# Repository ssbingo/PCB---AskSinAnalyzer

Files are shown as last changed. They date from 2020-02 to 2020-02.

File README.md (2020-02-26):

# PCB für den AskSinAnalyzer

## Bilder

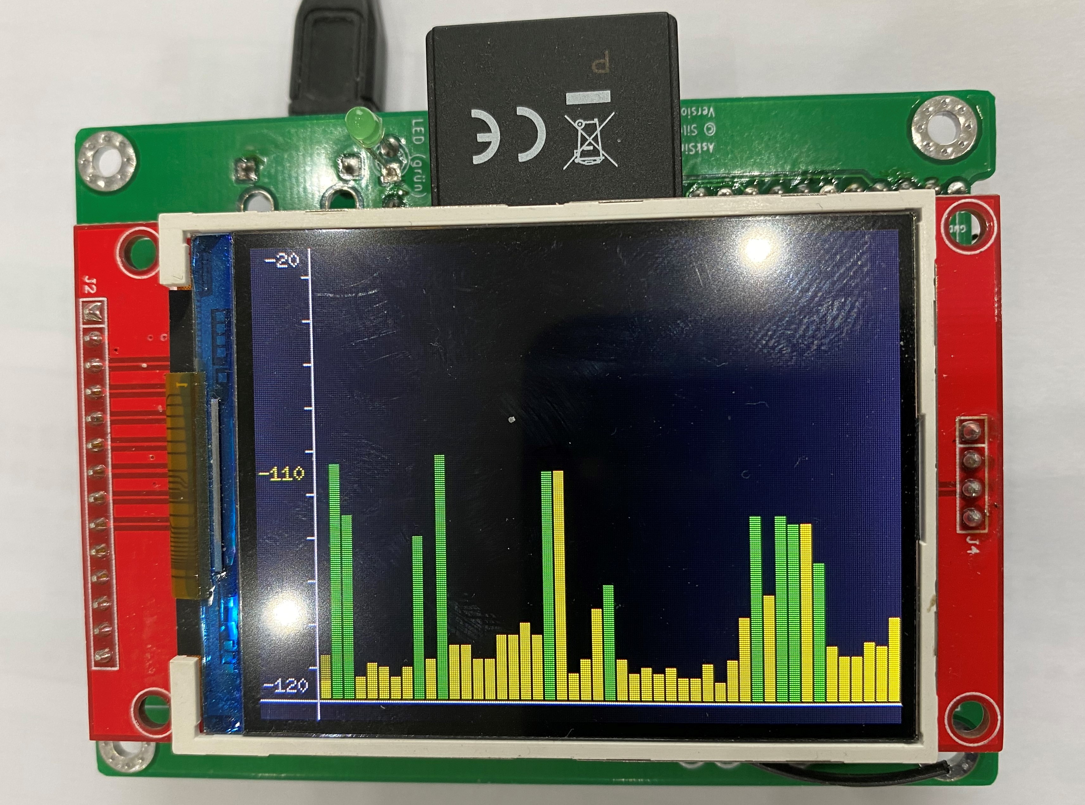
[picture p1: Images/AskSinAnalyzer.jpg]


## Schaltplan

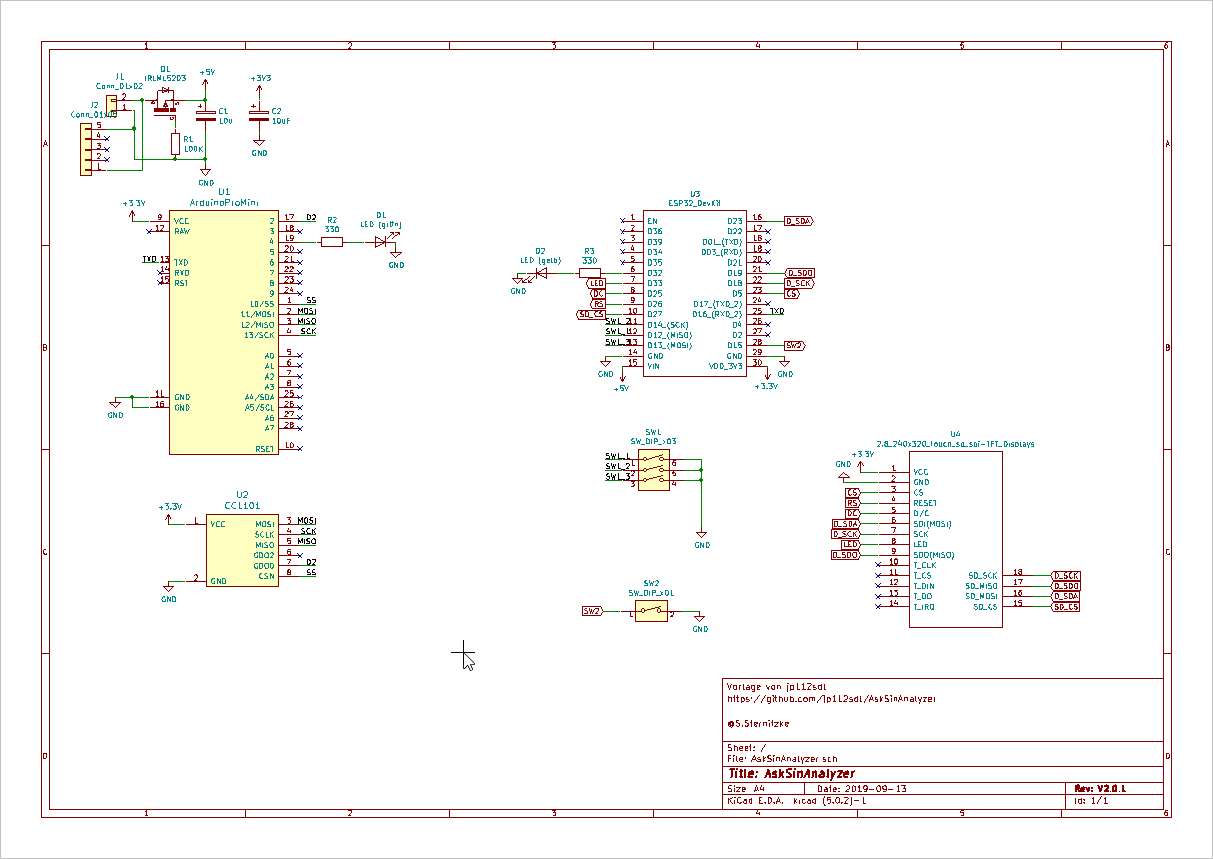
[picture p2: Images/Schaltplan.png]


[:arrow_right: Schaltplan](Images/Schaltplan.pdf)

## Platine

[:arrow_right: PCB Gerber](Platine/AskSinAnalyzer V2.0.3.zip)

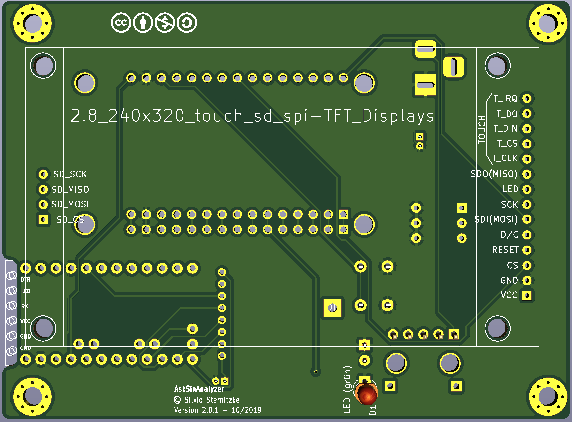
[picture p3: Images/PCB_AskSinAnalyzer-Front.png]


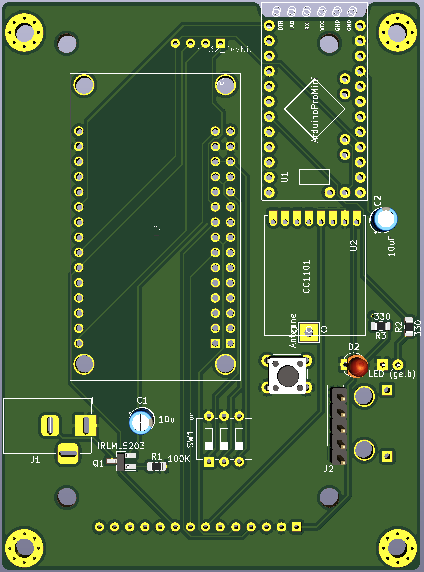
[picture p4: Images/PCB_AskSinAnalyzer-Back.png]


## Gehäuse

## Aufbau / Stückliste

### Der Aufbau
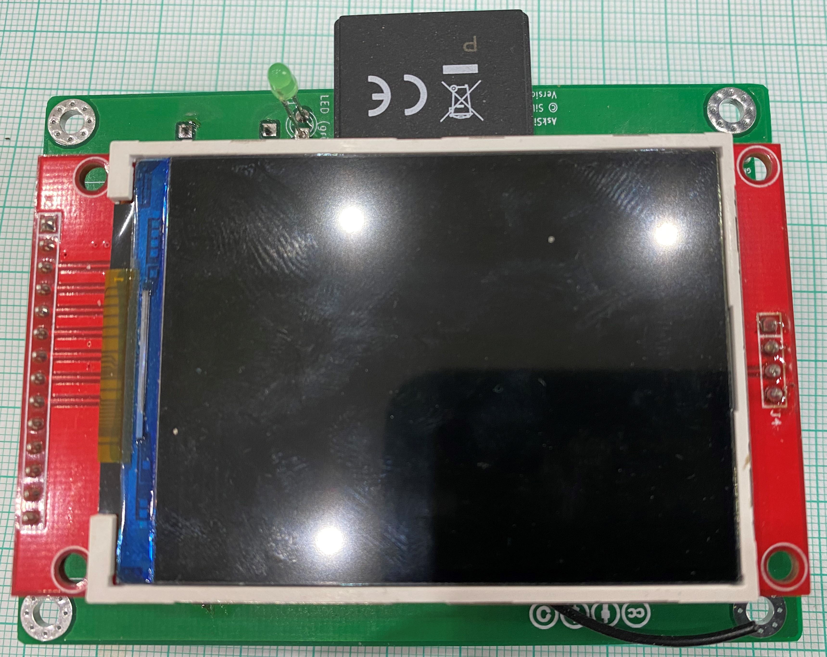
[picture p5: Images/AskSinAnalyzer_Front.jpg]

Bestückung Frontseite<br>

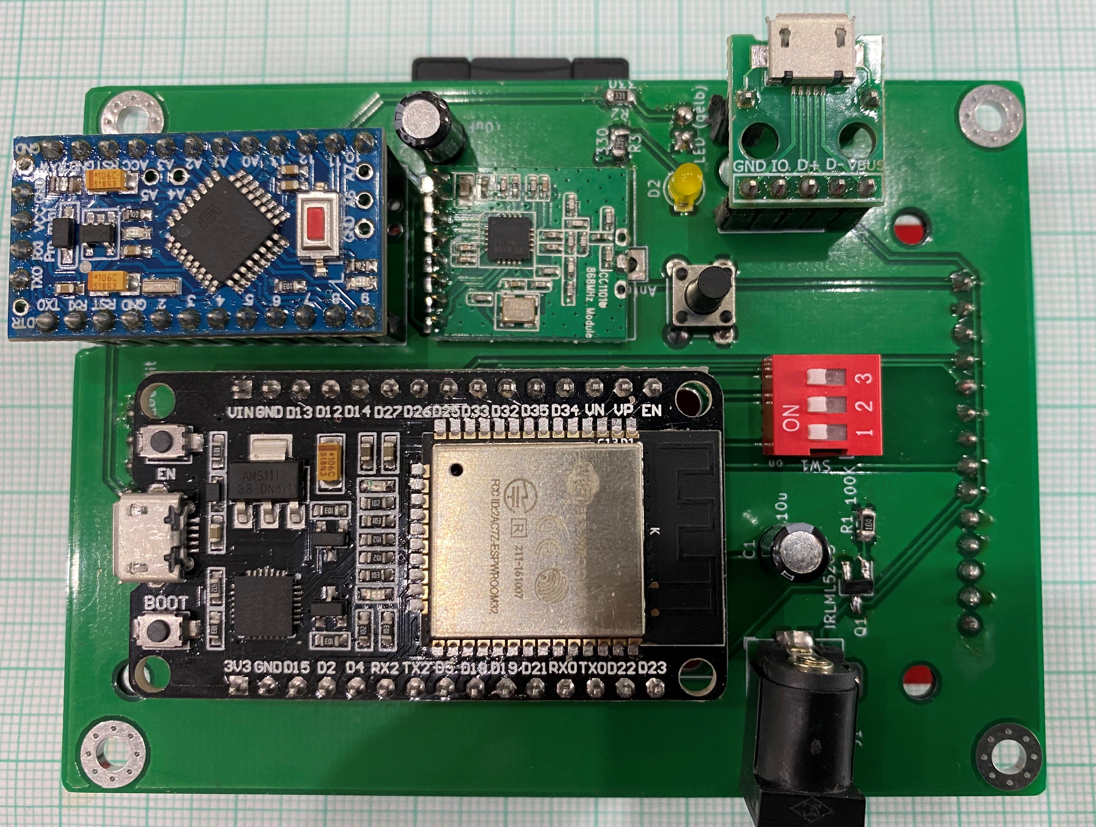
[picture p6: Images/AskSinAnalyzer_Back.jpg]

Bestückung Rückseite<br>
Hier gut zu erkennen, der verwendetet ESP32. Das PinOut ist etwas anders.<br>


AskSinnAnalyzer in Betrieb<br>

### Die benötigten Bauteile
| Bauteil | Link |
| ---|---|
|Bauteilliste Reichelt|[:arrow_right: Reichelt](https://www.reichelt.de/my/1678090) |
|Arduinio Pro mini 3.3V | |
|Funkmodul CC1101| |
|Display 2.8 mit SPI|[:arrow_right: Ebay](https://www.ebay.de/itm/322625783359) |

## Hinweise

- :exclamation: Der verwendete ESP32 hatte ein, gegenüber der Beschreibung im Projekt, etwas verändertetes Layout. siehe [Beitrag im Forum](https://homematic-forum.de/forum/viewtopic.php?f=76&t=51161&p=527419#p527456]

## Lizenz

**Creative Commons BY-NC-SA**<br>
Give Credit, NonCommercial, ShareAlike

<br />This work is licensed under a <a rel="license" href="http://creativecommons.org/licenses/by-nc-sa/4.0/">Creative Commons Attribution-NonCommercial-ShareAlike 4.0 International License</a>.

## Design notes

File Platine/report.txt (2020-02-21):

Plot-Datei „H:\Eigene Platinen (KiCAD)\Projekte\In Bearbeitung\AskSinAnalyzer V2\Platine\Gerber\AskSinAnalyzer-F.Cu.gbr“ erstellt.
Plot-Datei „H:\Eigene Platinen (KiCAD)\Projekte\In Bearbeitung\AskSinAnalyzer V2\Platine\Gerber\AskSinAnalyzer-B.Cu.gbr“ erstellt.
Plot-Datei „H:\Eigene Platinen (KiCAD)\Projekte\In Bearbeitung\AskSinAnalyzer V2\Platine\Gerber\AskSinAnalyzer-F.Paste.gbr“ erstellt.
Plot-Datei „H:\Eigene Platinen (KiCAD)\Projekte\In Bearbeitung\AskSinAnalyzer V2\Platine\Gerber\AskSinAnalyzer-B.Paste.gbr“ erstellt.
Plot-Datei „H:\Eigene Platinen (KiCAD)\Projekte\In Bearbeitung\AskSinAnalyzer V2\Platine\Gerber\AskSinAnalyzer-F.SilkS.gbr“ erstellt.
Plot-Datei „H:\Eigene Platinen (KiCAD)\Projekte\In Bearbeitung\AskSinAnalyzer V2\Platine\Gerber\AskSinAnalyzer-B.SilkS.gbr“ erstellt.
Plot-Datei „H:\Eigene Platinen (KiCAD)\Projekte\In Bearbeitung\AskSinAnalyzer V2\Platine\Gerber\AskSinAnalyzer-F.Mask.gbr“ erstellt.
Plot-Datei „H:\Eigene Platinen (KiCAD)\Projekte\In Bearbeitung\AskSinAnalyzer V2\Platine\Gerber\AskSinAnalyzer-B.Mask.gbr“ erstellt.
Plot-Datei „H:\Eigene Platinen (KiCAD)\Projekte\In Bearbeitung\AskSinAnalyzer V2\Platine\Gerber\AskSinAnalyzer-Edge.Cuts.gbr“ erstellt.

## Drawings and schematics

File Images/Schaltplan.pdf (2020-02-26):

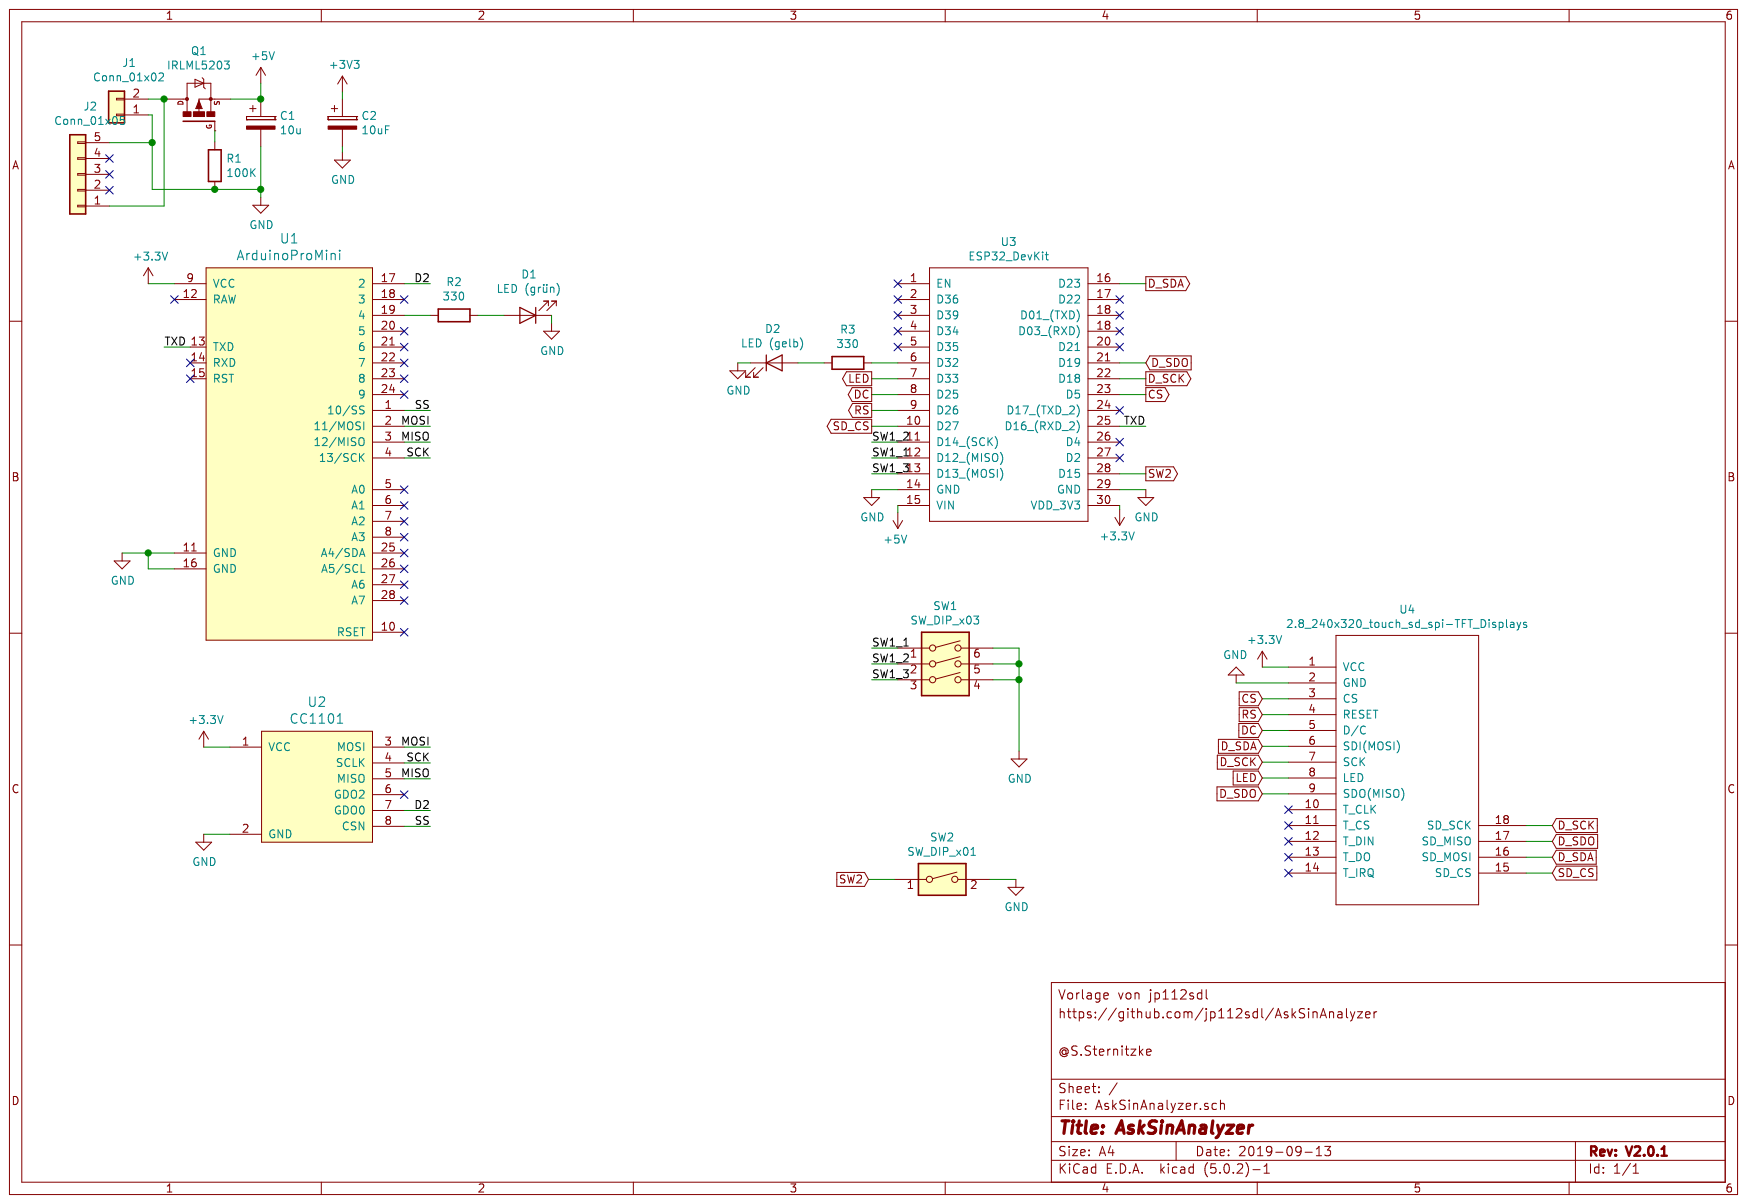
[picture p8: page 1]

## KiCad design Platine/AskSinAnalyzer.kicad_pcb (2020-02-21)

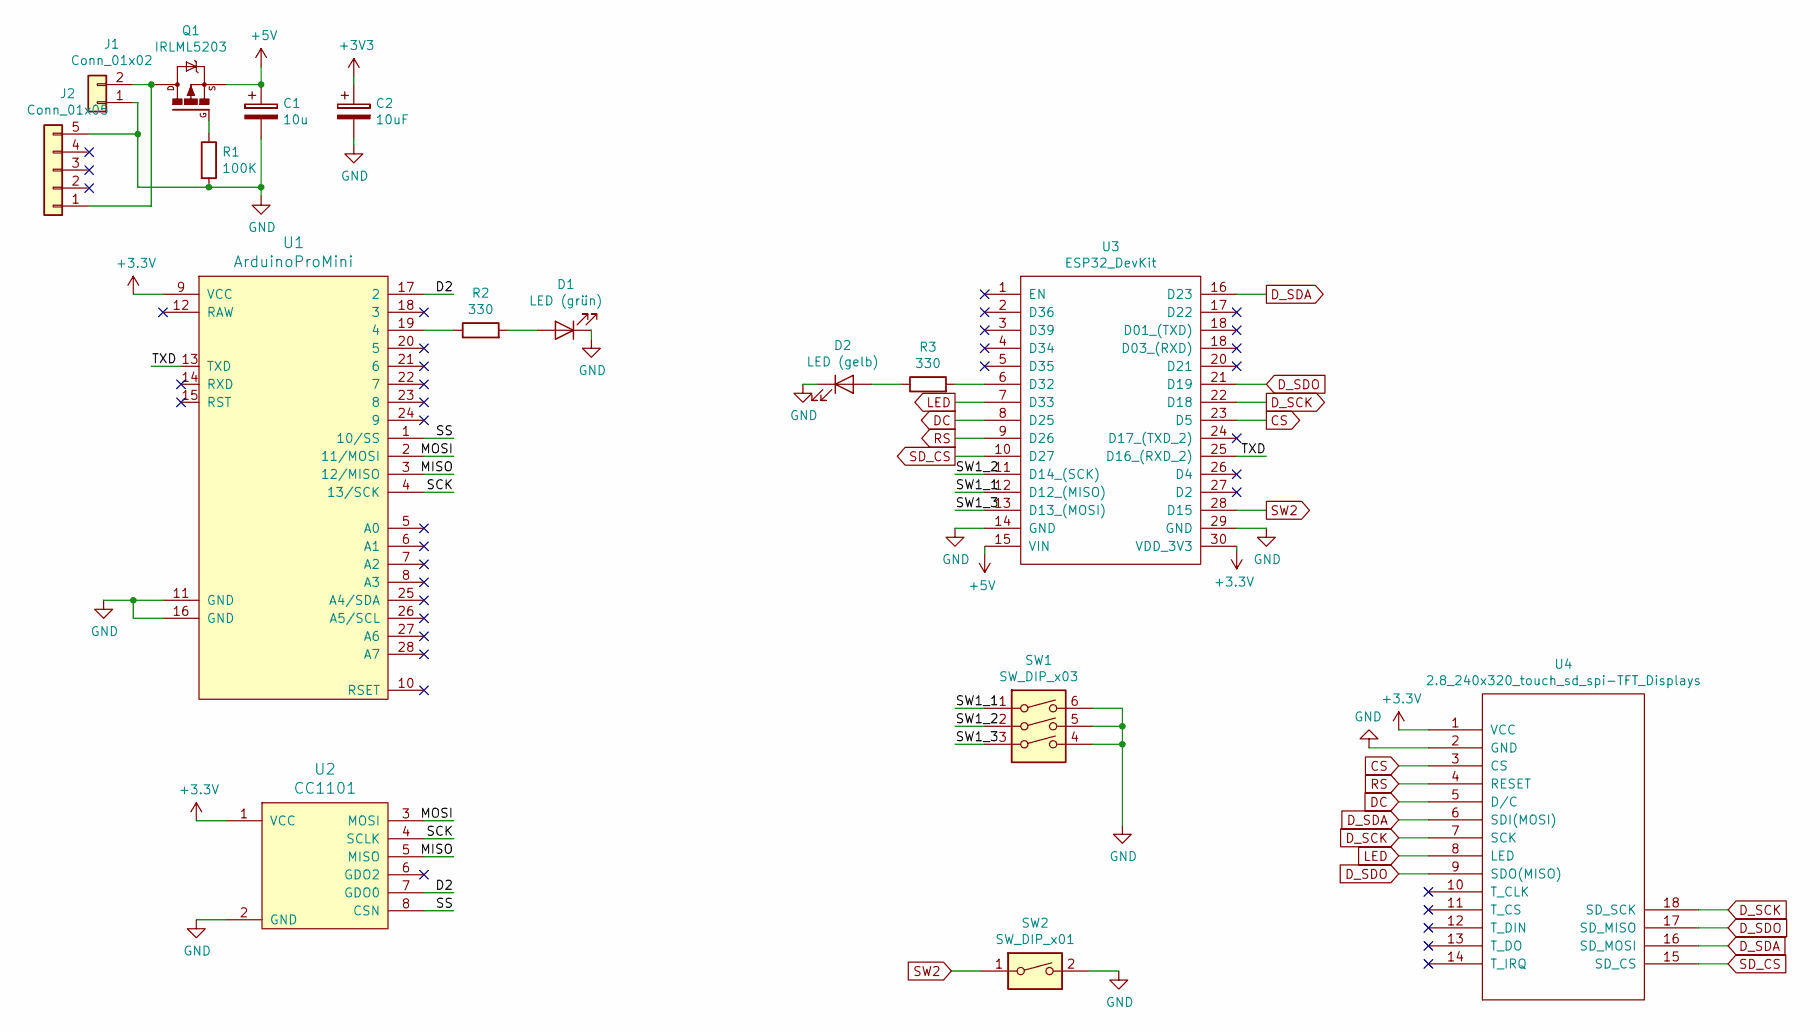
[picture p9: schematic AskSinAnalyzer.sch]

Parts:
C1: 10u; CP_Radial_D4.0mm_P1.50mm
C2: 10uF; CP_Radial_D4.0mm_P1.50mm
D1: LED (grün); LED_D3.0mm
D2: LED (gelb); LED_D3.0mm
J1: Conn_01x02; BarrelJack_Horizontal
J2: Conn_01x05; USBMicroBoard
Q1: IRLML5203; SOT-23_Handsoldering
R1: 100K; R_0805_2012Metric_Pad1.15x1.40mm_HandSolder
R2, R3: 330; R_0805_2012Metric_Pad1.15x1.40mm_HandSolder
SW1: SW_DIP_x03; SW_DIP_SPSTx03_Slide_6.7x9.18mm_W7.62mm_P2.54mm_LowProfile
SW2: SW_DIP_x01; SW_PUSH_6mm_H5mm
U1: ArduinoProMini
U2: CC1101
U3: ESP32_DevKit; MODULE_ESP32-DEVKITC-32D_dual
U4: 2.8_240x320_touch_sd_spi-TFT_Displays; 2.8_tft_240x320_touch_sd_spi

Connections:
+5V: C1.1, Q1.2 (S), U3.15 (VIN)
/D2: U1.17 (2), U2.7 (GDO0)
/MISO: U1.3 (12/MISO), U2.5 (MISO)
/MOSI: U1.2 (11/MOSI), U2.3 (MOSI)
/SCK: U1.4 (13/SCK), U2.4 (SCLK)
/SS: U1.1 (10/SS), U2.8 (CSN)
/SW1_1: SW1.1, U3.12 (D12_(MISO))
/SW1_2: SW1.2, U3.11 (D14_(SCK))
/SW1_3: SW1.3, U3.13 (D13_(MOSI))
/TXD: U1.13 (TXD), U3.25 (D16_(RXD_2))
CS: U3.23 (D5), U4.3 (CS)
DC: U3.8 (D25), U4.5 (D/C)
D_SCK: U3.22 (D18), U4.7 (SCK), U4.18 (SD_SCK)
D_SDA: U3.16 (D23), U4.6 (SDI(MOSI)), U4.16 (SD_MOSI)
D_SDO: U3.21 (D19), U4.9 (SDO(MISO)), U4.17 (SD_MISO)
GND: C1.2, C2.2, D1.1 (K), D2.1 (K), J1.1, J2.5, R1.2, SW1.4, SW1.5, SW1.6, SW2.2, U1.11 (GND), U1.16 (GND), U2.2 (GND), U3.14 (GND), U3.29 (GND), U4.2 (GND)
LED: U3.7 (D33), U4.8 (LED)
unnamed: D1.2 (A), R2.2
unnamed: D2.2 (A), R3.1
unnamed: J1.2, J2.1, Q1.3 (D)
unnamed: Q1.1 (G), R1.1
unnamed: R2.1, U1.19 (4)
unnamed: R3.2, U3.6 (D32)
RS: U3.9 (D26), U4.4 (RESET)
SD_CS: U3.10 (D27), U4.15 (SD_CS)
SW2: SW2.1, U3.28 (D15)

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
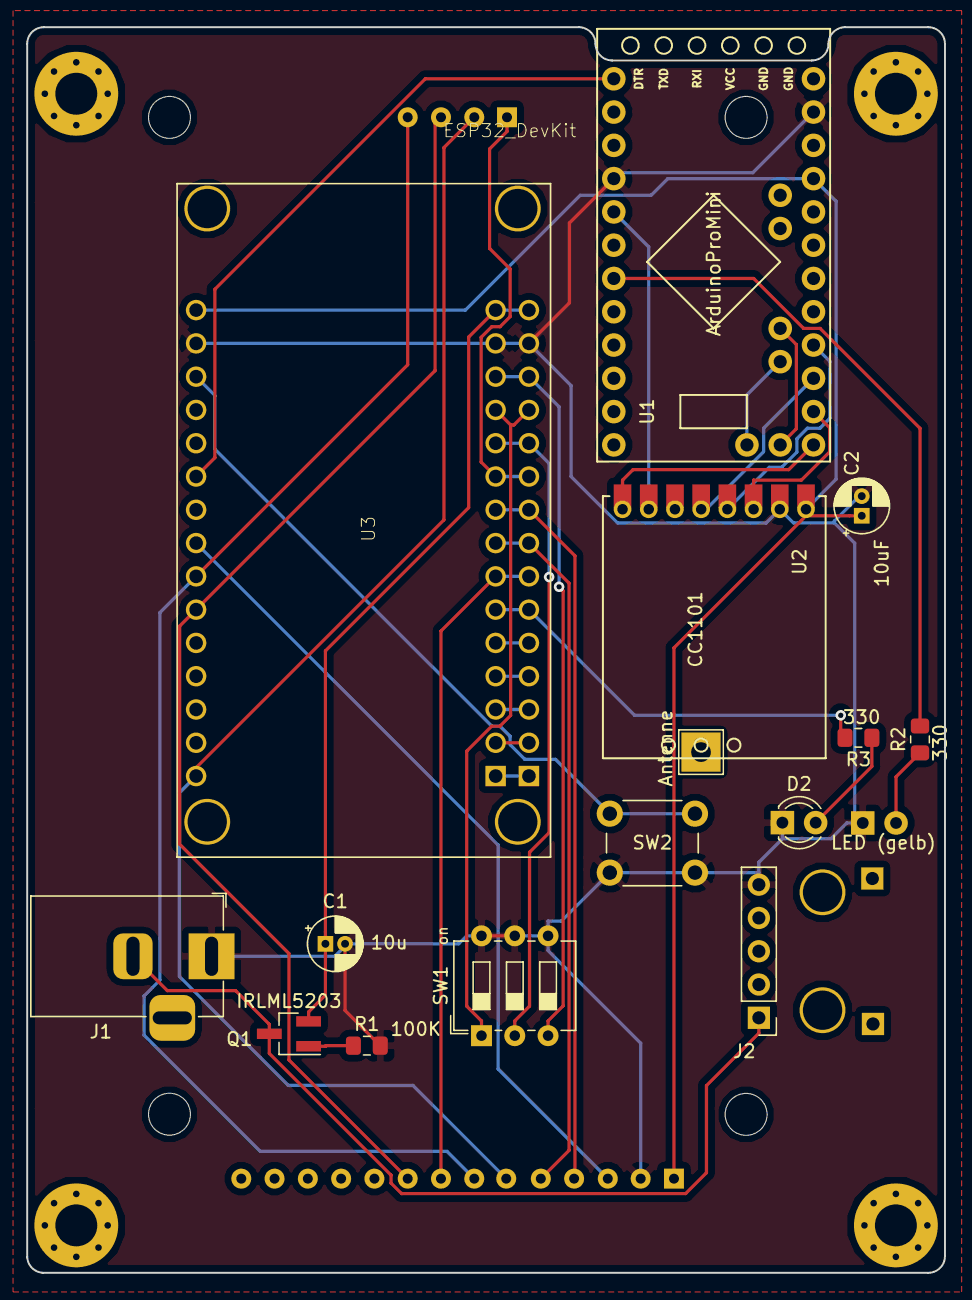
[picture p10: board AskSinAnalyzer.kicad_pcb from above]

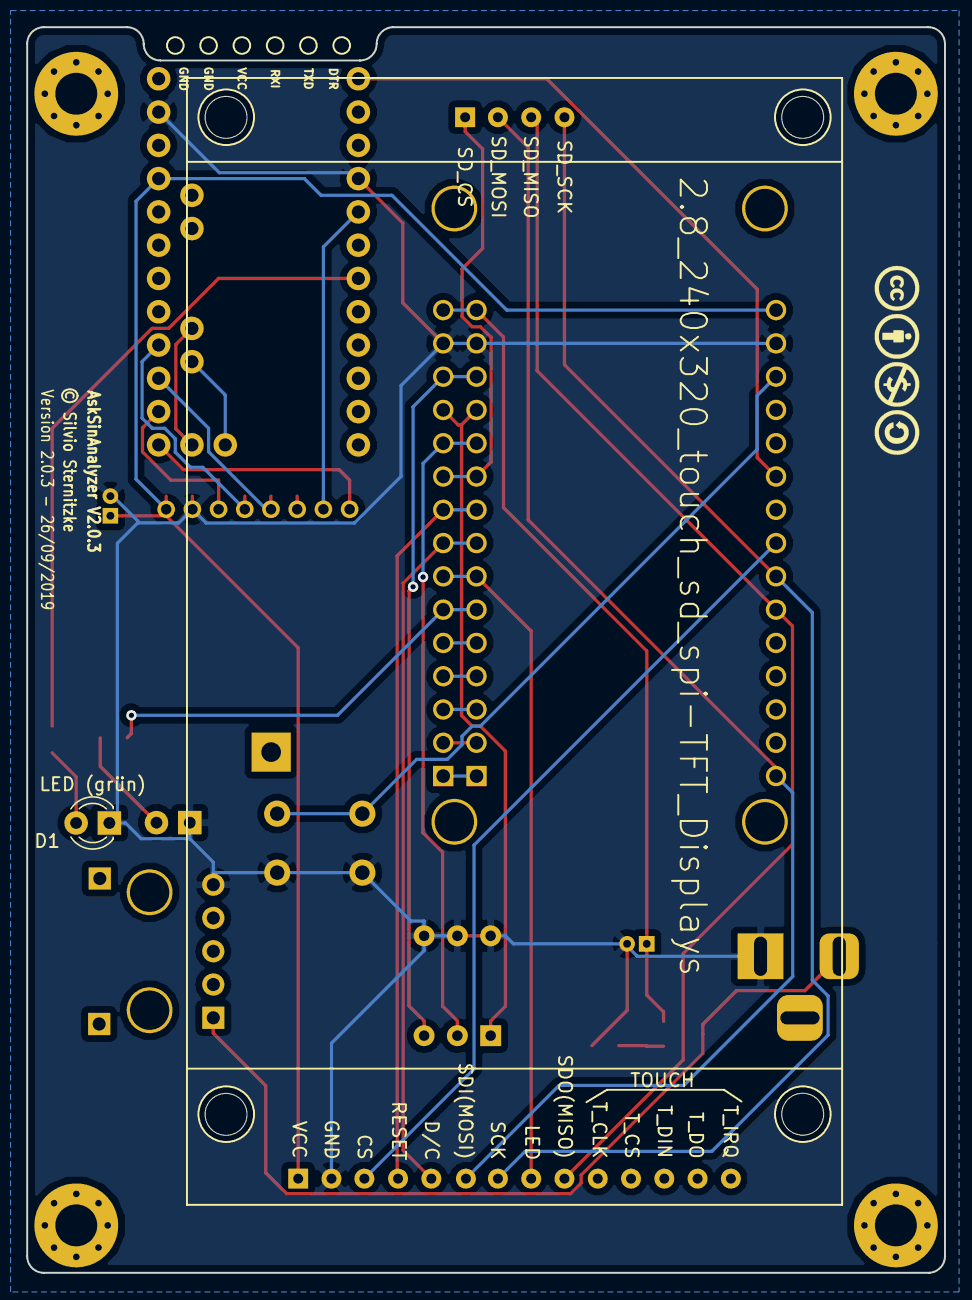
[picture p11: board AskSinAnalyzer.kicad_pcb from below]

Board: 2 copper layers, 70.0 x 95.1 mm, 26 parts (2 on the bottom side), 27 nets.

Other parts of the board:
Antenne: TestPoint_THTPad_3.0x3.0mm_Drill1.5mm
Copy: Version 2.0.3 - 26/09/2019; Copyrigth
REF01, REF02, REF03, REF04: MountingHole_3.2mm_M3_Pad_Via
REF020, REF021, REF022, REF23: MountingHole_3.2mm_M3

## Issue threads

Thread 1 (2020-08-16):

PCB für den AskSinAnalyzer Pinout

Michel83, 2020-08-16:
Hi,

gibt es irgendwo eine kleine anleitung was am Pinout geändert werden muss.

Grüße
Mike

Michel83, 2020-08-18:
Alles ok, läuft ohne Probleme

Closed 2020-08-18.

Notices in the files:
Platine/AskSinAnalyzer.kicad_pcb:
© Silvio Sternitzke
